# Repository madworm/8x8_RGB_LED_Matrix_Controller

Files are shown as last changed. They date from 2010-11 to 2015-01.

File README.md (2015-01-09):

8x8_RGB_LED_Matrix_Controller
=============================

LAYOUT FILES: 8x8-RGB-LED-Matrix controller using 4x 74HC595 shift registers. CPU: ATmega168/328. Arduino 'compatible'. Runs with code from [V3_x_boards_test](https://github.com/madworm/V3_x_boards_test) repo. KICAD and Gerber files.

---

Before having PC-boards made, please make sure you know about your manufacturer's peculiarities!
Especially drill-sizes and their tolerances may vary too much and give you trouble.

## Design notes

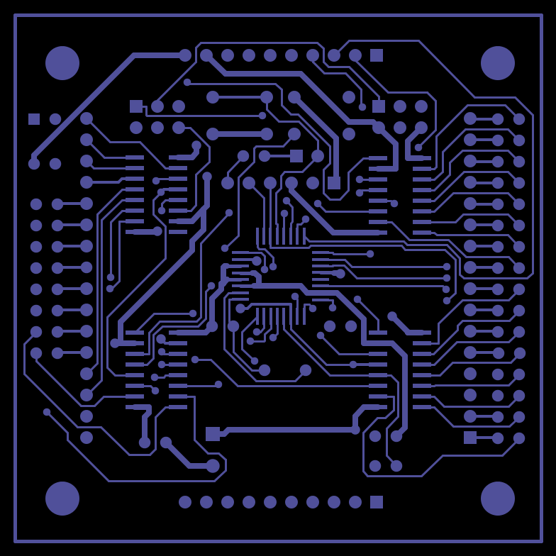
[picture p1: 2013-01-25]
gerber_files/PNGs/8x8_rgb_matrix-V3_04-Front.gtl.png

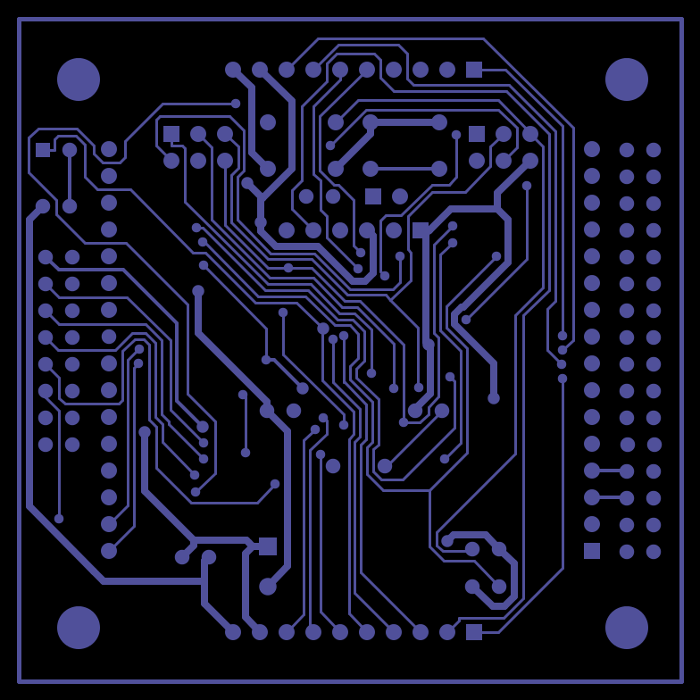
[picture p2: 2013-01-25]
gerber_files/PNGs/8x8_rgb_matrix-V3_04-Back.gbl.png

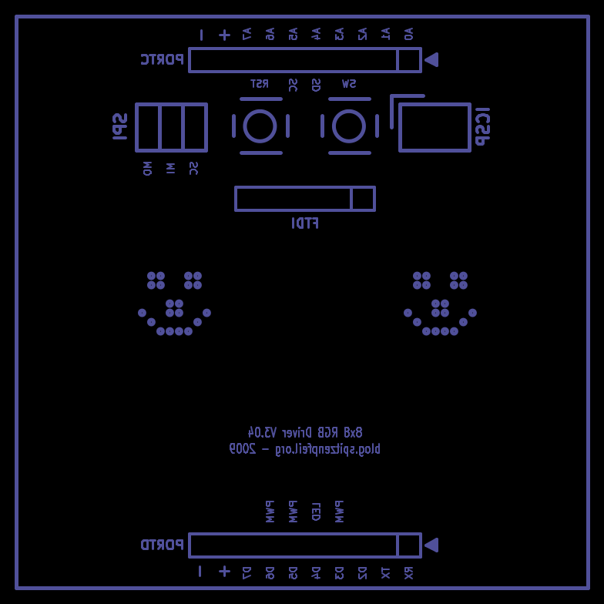
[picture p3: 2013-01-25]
gerber_files/PNGs/8x8_rgb_matrix-V3_04-B_SilkS.gbo.png

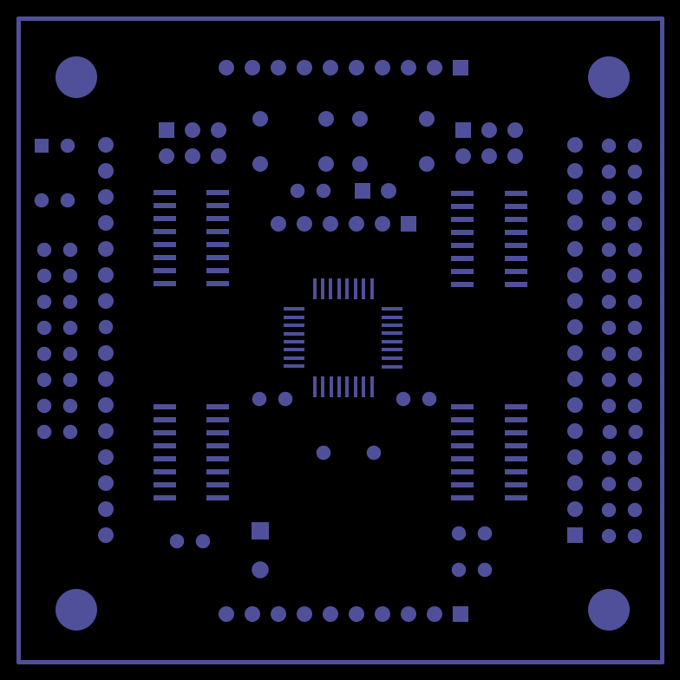
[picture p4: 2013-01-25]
gerber_files/PNGs/8x8_rgb_matrix-V3_04-F_Mask.gts.png

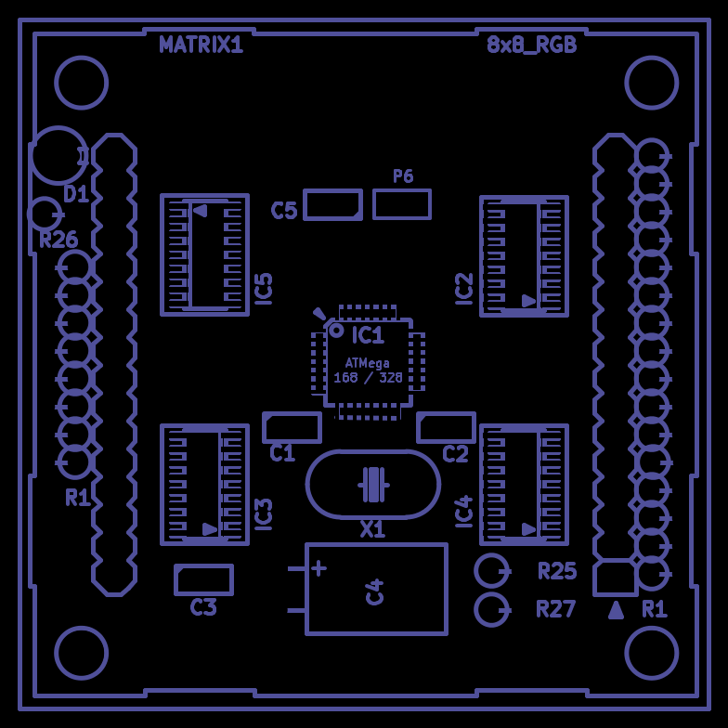
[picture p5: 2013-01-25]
gerber_files/PNGs/8x8_rgb_matrix-V3_04-F_SilkS.gto.png

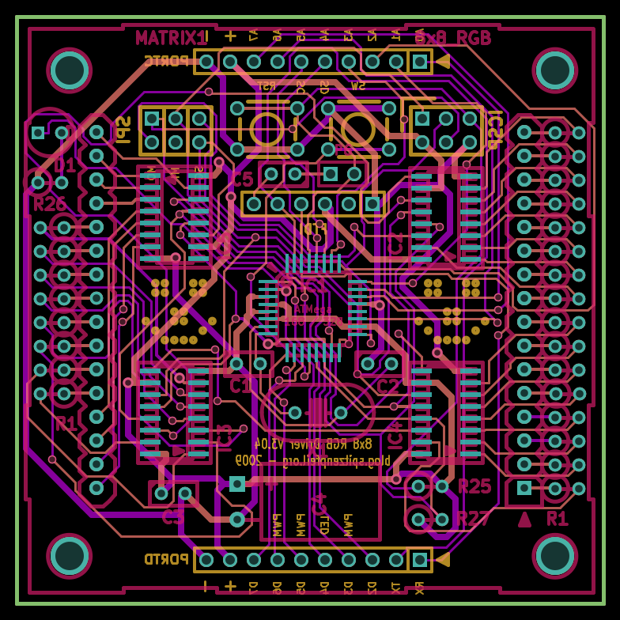
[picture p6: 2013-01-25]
gerber_files/PNGs/8x8_rgb_matrix-V3_04.png

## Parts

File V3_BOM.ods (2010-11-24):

Description: | Amount per board: | From: | Order part #: | Order amount: | Effective per board: | Rebate ? | Cost per part #: | Currency: | Effective per board: | Currency:
shipping costs for my orders | 1.000 | -- | -- | -- | 1.000 | -- | 2.350 | € | 2.350 | €
board | 1.000 | goldphoenix | __my_part__ | 10.000 | 1.000 | -- | 5.083 | € | 5.083 | €
led matrix | 1.000 | ledsee.com | RGBMATRIX | 10.000 | 1.000 | -- | 11.900 | € | 11.900 | €
10k Ohm | 2.000 | reichelt.de | METALL 10,0K | 20.000 | 2.000 | ab 1: 8.2 ¢, ab 10: 4.9¢, ab 100: 2.5¢, ab 1000: 1.6¢ | 0.049 | € | 0.098 | €
47µF | 1.000 | reichelt.de | RAD 47/35 | 10.000 | 1.000 | -- | 0.041 | € | 0.041 | €
100nF | 2.000 | reichelt.de | MKS-02 100N | 20.000 | 2.000 | -- | 0.120 | € | 0.240 | €
22pF | 2.000 | reichelt.de | KERKO 22P | 20.000 | 2.000 | -- | 0.040 | € | 0.080 | €
anti static bag | 0.010 | reichelt.de | ESD BEUTEL-P 150 | just once ! | 0.010 | -- | 6.000 | € | 0.060 | €
LED green 3mm | 1.000 | reichelt.de | LED 3MM GN | 10.000 | 1.000 | -- | 0.051 | € | 0.051 | €
270 Ohm | 24.000 | reichelt.de | METALL 270 | 240.000 | 24.000 | ab 1: 8.2 ¢, ab 10: 4.9¢, ab 100: 2.5¢, ab 1000: 1.6¢ | 0.025 | € | 0.600 | €
1k Ohm | 1.000 | reichelt.de | METALL 1,00K | 10.000 | 1.000 | ab 1: 8.2 ¢, ab 10: 4.9¢, ab 100: 2.5¢, ab 1000: 1.6¢ | 0.049 | € | 0.049 | €
quartz 16MHz | 1.000 | reichelt.de | 16,0000-HC49U-S | 10.000 | 1.000 | -- | 0.150 | € | 0.150 | €
3x2 male header | 2.000 | reichelt.de | SL 2X40G 2,54 | 2.000 | 0.150 | -- | 0.290 | € | 0.044 | €
10pin female header | 2.000 | reichelt.de | BL 1X10G8 2,54 | 20.000 | 2.000 | -- | 0.120 | € | 0.240 | €
74HC595 SMD | 4.000 | reichelt.de | SMD HC 595 | 40.000 | 4.000 | -- | 0.140 | € | 0.560 | €
lph switch | 2.000 | reichelt.de | TASTER 9302 | 20.000 | 2.000 | -- | 0.120 | € | 0.240 | €
6x1 male header | 1.000 | reichelt.de | SL 1X40G 2,54 | 2.000 | 0.150 | -- | 0.110 | € | 0.017 | €
2x1 male header | 1.000 | reichelt.de | SL 1X40G 2,54 | user leftovers ! | 0.050 | -- | 0.110 | € | 0.006 | €
atmega168 | 1.000 | segor.de | ATmega 168-20AU | 10.000 | 1.000 | ab 1: 4.00€, ab 10: 3.20€, ab 25: 2.80€ | 3.200 | € | 3.200 | €
8pin female precision header | 4.000 | segor.de | FLLAB 1x 8-180G | 40.000 | 4.000 | ab 1: 50¢, ab 10: 41¢, ab 25: 39¢ | 0.390 | € | 1.560 | €
quartz spacer | 1.000 | segor.de | Q-Isoscheibe | 10.000 | 1.000 | ab 1: 10¢, ab 10: 8¢ | 0.080 | € | 0.080 | €
low profile jumper h=4mm | 4.000 | segor.de | Mini-Jumper | 40.000 | 4.000 | ab 1: 10¢, ab 10: 8¢, ab 25: 8¢, ab 100: 7¢ | 0.080 | € | 0.320 | €
 |  |  |  |  |  |  |  | Total € | 26.967 |  | --> 28 €
 |  |  |  |  |  |  |  | € / USD | 1.330
 |  |  |  |  |  |  |  | Total USD | 35.867
Number of boards to make: |  | 10.000
Shipping costs reichelt.de |  | 5.900 | €
Shipping cost segor.de |  | 6.000 | € |  | 1x melka
Shpping cost ledsee.com |  | 11.603 | € |  | 1x nick
Shipping cost for my orders |  | 23.503 | € |  | 1x dra
 |  |  |  |  | 1x jason
last price update: OUTDATED !

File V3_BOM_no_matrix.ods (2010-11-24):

Description: | Amount per board: | From: | Order part #: | Order amount: | Effective per board: | Rebate ? | Cost per part #: | Currency: | Effective per board: | Currency:
shipping costs for my orders | 1.000 | -- | -- | -- | 1.000 | -- | 0.464 | € | 0.464 | €
board | 1.000 | goldphoenix | __my_part__ | 25.000 | 1.000 | -- | 5.083 | € | 5.083 | €
10k Ohm | 2.000 | reichelt.de | METALL 10,0K | 50.000 | 2.000 | ab 1: 8.2 ¢, ab 10: 4.9¢, ab 100: 2.5¢, ab 1000: 1.6¢ | 0.049 | € | 0.098 | €
47µF | 1.000 | reichelt.de | RAD 47/35 | 25.000 | 1.000 | -- | 0.040 | € | 0.040 | €
100nF | 2.000 | reichelt.de | MKS-02 100N | 50.000 | 2.000 | -- | 0.150 | € | 0.300 | €
22pF | 2.000 | reichelt.de | KERKO 22P | 50.000 | 2.000 | -- | 0.060 | € | 0.120 | €
anti static bag | 0.010 | reichelt.de | ESD BEUTEL-P 150 | just once ! | 0.010 | -- | 6.000 | € | 0.060 | €
LED green 3mm | 1.000 | reichelt.de | LED 3MM GN | 25.000 | 1.000 | -- | 0.060 | € | 0.060 | €
270 Ohm | 24.000 | reichelt.de | METALL 270 | 600.000 | 24.000 | ab 1: 8.2 ¢, ab 10: 4.9¢, ab 100: 2.5¢, ab 1000: 1.6¢ | 0.025 | € | 0.600 | €
1k Ohm | 1.000 | reichelt.de | METALL 1,00K | 25.000 | 1.000 | ab 1: 8.2 ¢, ab 10: 4.9¢, ab 100: 2.5¢, ab 1000: 1.6¢ | 0.049 | € | 0.049 | €
quartz 16MHz | 1.000 | reichelt.de | 16,0000-HC49U-S | 25.000 | 1.000 | -- | 0.180 | € | 0.180 | €
3x2 male header | 2.000 | reichelt.de | SL 2X40G 2,54 | 4.000 | 0.150 | -- | 0.270 | € | 0.041 | €
10pin female header | 2.000 | reichelt.de | BL 1X10G8 2,54 | 50.000 | 2.000 | -- | 0.140 | € | 0.280 | €
74HC595 SMD | 4.000 | reichelt.de | SMD HC 595 | 100.000 | 4.000 | -- | 0.170 | € | 0.680 | €
lph switch | 2.000 | reichelt.de | TASTER 9302 | 50.000 | 2.000 | -- | 0.130 | € | 0.260 | €
6x1 male header | 1.000 | reichelt.de | SL 1X40G 2,54 | 5.000 | 0.150 | -- | 0.120 | € | 0.018 | €
2x1 male header | 1.000 | reichelt.de | SL 1X40G 2,54 | user leftovers ! | 0.050 | -- | 0.120 | € | 0.006 | €
atmega168 | 1.000 | segor.de | ATmega 168-20AU | 25.000 | 1.000 | ab 1: 4.00€, ab 10: 3.20€, ab 25: 2.80€ | 2.800 | € | 2.800 | €
8pin female precision header | 4.000 | segor.de | FLLAB 1x 8-180G | 100.000 | 4.000 | ab 1: 50¢, ab 10: 40¢, ab 25: 38¢, ab 100: 35¢ | 0.350 | € | 1.400 | €
quartz spacer | 1.000 | segor.de | Q-Isoscheibe | 25.000 | 1.000 | ab 1: 10¢, ab 10: 8¢ | 0.080 | € | 0.080 | €
low profile jumper h=4mm | 4.000 | segor.de | Mini-Jumper | 100.000 | 4.000 | ab 1: 10¢, ab 10: 8¢, ab 25: 8¢, ab 100: 7¢ | 0.080 | € | 0.320 | €
 |  |  |  |  |  |  |  | Total € | 12.938 |  | --> 16.50 €
 |  |  |  |  |  |  |  | € / USD | 1.330
 |  |  |  |  |  |  |  | Total USD | 17.208
Number of boards to make: |  | 25.000
Shipping costs reichelt.de |  | 5.600 | €
Shipping cost segor.de |  | 6.000 | €
Shipping cost for my orders |  | 11.600 | €
last price update: 06-07-2009

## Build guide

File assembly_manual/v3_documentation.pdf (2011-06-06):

V3.x Matrix Controller assembly instructions

### 1. List of Parts:

- IC1 | Atmega168-20AU, TQFP 32 7x7 ( Mouser: 556-ATMEGA168-20AU )
- IC2-5 | 74HC595, ST EZ80731, SO16
- C1-2 | 22pF, should match X1
- C3,C5 | 100nF ( Mouser: 505-MKS02.1/63/10 )
- C4 | 47µF ( Mouser: 75-515D474M050JA6AE3 )
- R25,R27 | 10k
- R26 | 1k
- D1 | LED, 3mm
- RE | reset enable, 2pin male header (cut to size) + low profile jumper
- R1-24 | suitable resistors for RGB LEDs. 270Ω may work for all
- MATRIX | 4x 8pin female header
- PORTC/D | 2x 10pin female header
- ICSP | 1x 2x3pin male header
- SPI | 1x 2x3pin male header + 3 jumper
- SW,RST | general purpose switch, Schurter 1301.9302 ( Farnell: 1217773 )
- FTDI | 6pin male header
- X1 | 16MHz Quartz, HC49U-S package, low profile ! ( Mouser: 520-HCU1600-SX )
- spacer | Quartz spacer, non conductive ( or piece of plastic under the quartz, e.g. laser transparency )

When you buy the parts, make sure none of the components consume more than 7.5mm of height when assembled. Depending on the type of LED matrix you use, “standing” through hole resistors may have to be bent sideways at an angle of about 20-30°. Using small size resistors is an alternative if you can get them.

### 2. You will need:

- Soldering iron with a tip suitable for 0.5-0.8mm traces, not too small
- Solder with flux core, preferably "no clean", about 0.5-0.8mm diameter
- Additional "no clean" flux, in a syringe or dispenser pen
- wire cutter, tweezers
- strong magnifier for solder joint inspection
- cotton swabs + isopropyl alcohol for removing residual flux
- Programmer to flash the bootloader. Adafruit.com USBtinyISP works just fine
- USB/TTL serial adapter with DTR for auto-reset

### 3. Tips:

- Align the SMD parts as good as possible or you will have "lots of fun"
- Always use plenty of flux
- Always clean the tip
- Don't rush it

### 4. Suggested assembly steps:

- Start with the first group of parts with numbers 1 – 6 to build a minimal working system
- Flash the bootloader
- Continue to attach the remaining 4 SMT chips in group 7
- Now just follow the numbers until done.

If you want to change the order of attaching parts I'd put on the SMT chips first. If you put them on after the headers and other through hole parts you'll have "a lot of fun" while avoiding to burn holes into various components.

### 5. Suggested USB/TTL serial adapters:

- ModernDevice "BUB" ( http://www.moderndevice.com )
- Sparkfun "FTDI Basic Breakout – 5V" ( http://www.sparkfun.com )
- FTDI cable FTDI-TTL-232R-3V3 (works too, but no auto-reset)

### 6. Compatible RGB LED matrices:

- http://stores.ebay.com/LEDSEE-electronics
- http://www.seeedstudio.com

### 7. Please avoid:

- applying more than 5V DC (regulated) may destroy the device terminally
- do not reverse polarization of the USB adapter (pin 1 = GND)
- shorting pins to 5V/GND when set as OUTPUT may destroy the pin / chip
- do not power solenoids / relays without a transistor / protection diode
- in case of doubt, use a 1k resistor instead of just a blank wire
- isopropyl alcohol may decompose the transparent resin of the LED matrix

### 8. Pin assignment:

- The LED is connected to PD4 / digital IN/OUT 4
- The general purpose button is connected to PB0 / digital IN/OUT 8
- I²C / TWI (two wire): SDA, SCL

“PORTC” :

“PORTD” :

PIN NAME FUNCTION ARDUINO PIN | ARDUINO PIN
1 | PC0 | ADC0 | analog IN 0 digital IN/OUT 14
2 | PC1 | ADC1 | analog IN 1 digital IN/OUT 15
3 | PC2 | ADC2 | analog IN 2 digital IN/OUT 16
4 | PC3 | ADC3 | analog IN 3 digital IN/OUT 17
5 | PC4 ADC4, SDA analog IN 4 digital IN/OUT 18
6 | PC5 ADC5, SCL analog IN 5 digital IN/OUT 19
7 ADC6 | ADC6 | analog IN 6 | -
8 ADC7 | ADC7 | analog IN 7 | -
9 | + | 5V | - | -
10 | - | GND | - | -
PIN NAME | FUNCTION | ARDUINO PIN | ARDUINO PIN
1 | PD0 | RXD | RXD | digital IN/OUT 0
2 | PD1 | TXD | TXD | digital IN/OUT 1
3 | PD2 | INT0 | - | digital IN/OUT 2
4 | PD3 | INT1, OC2B | PWM | digital IN/OUT 3
5 | PD4 | XCK, T0 | onboard LED digital IN/OUT 4
6 | PD5 | T1, OC0B | PWM | digital IN/OUT 5
7 | PD6 | AIN0, OC0A | PWM | digital IN/OUT 6
8 | PD7 | AIN1 | - | digital IN/OUT 7
9 | + | 5V | - | -
10 | - | GND | - | -

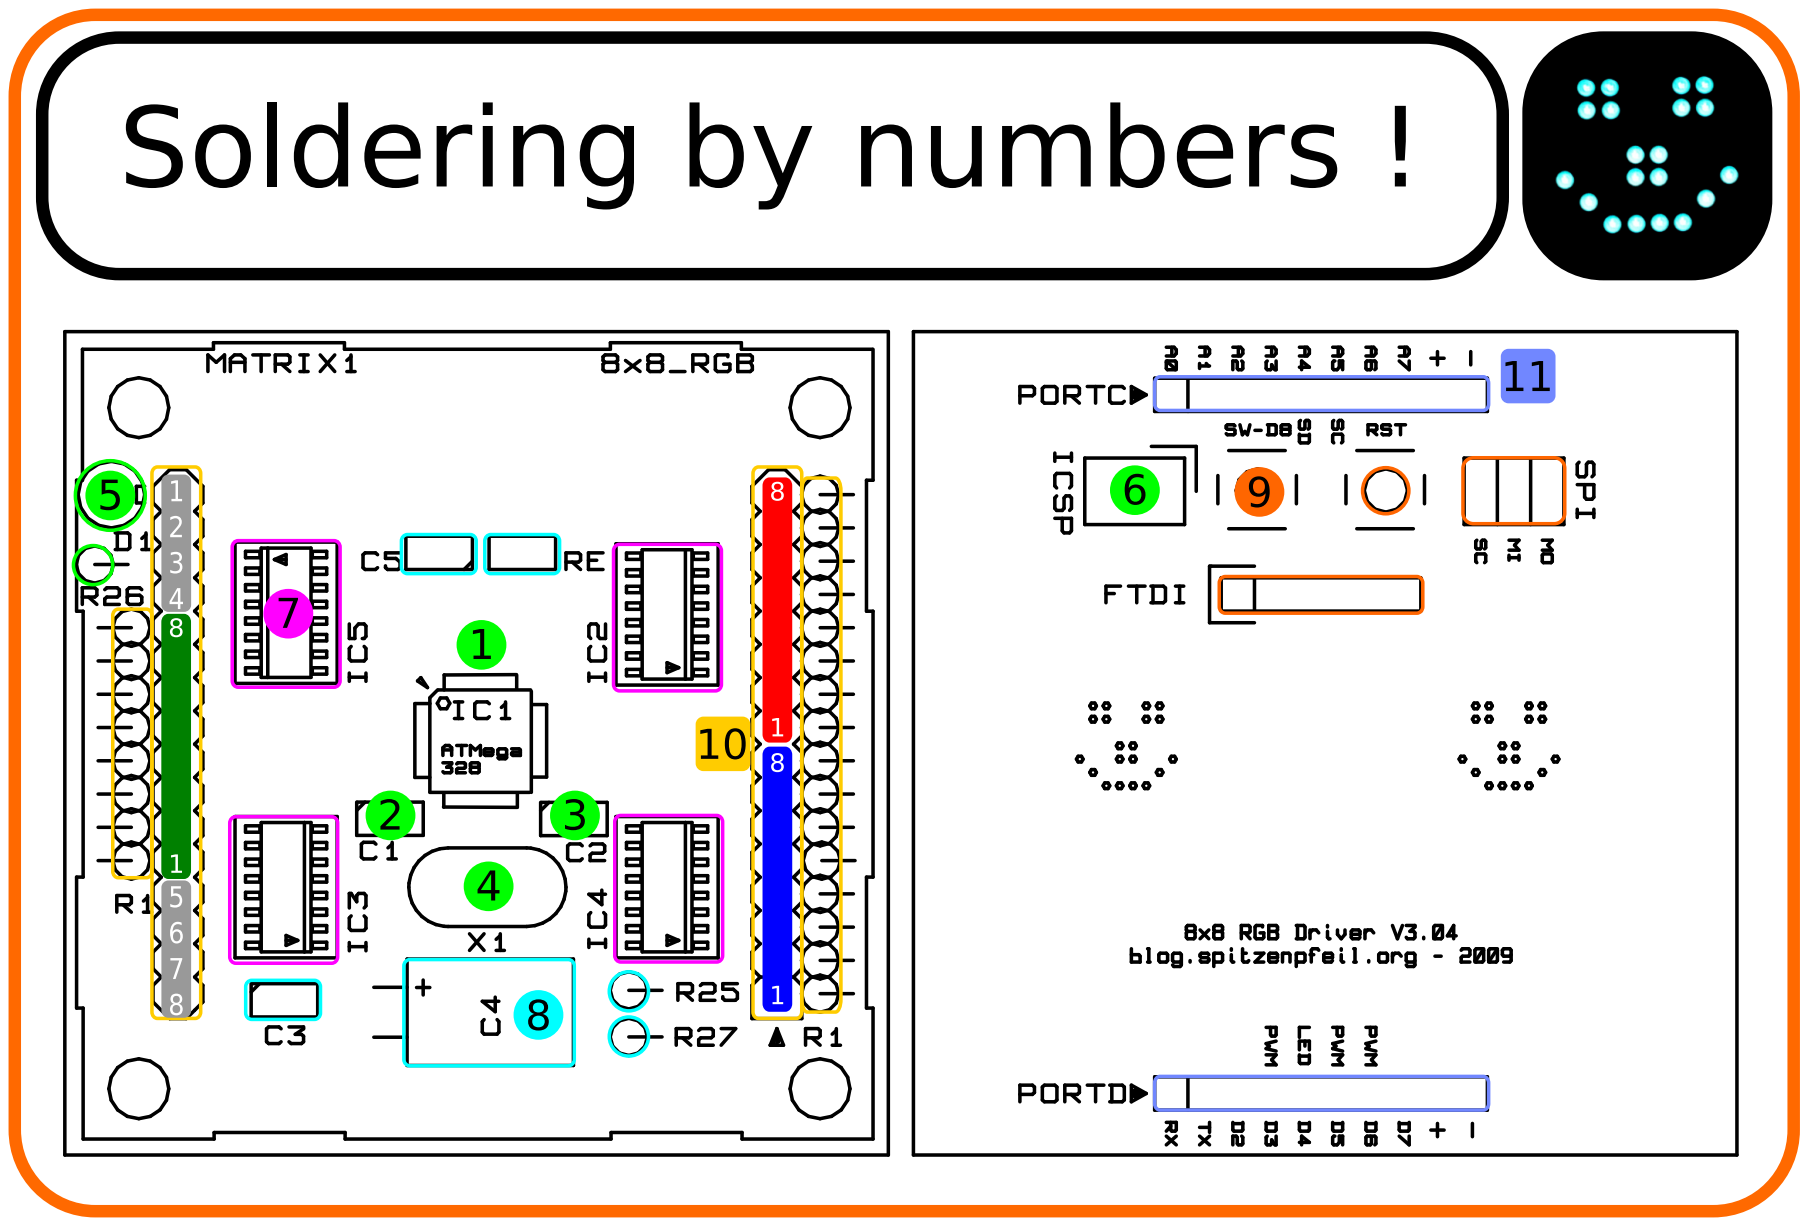
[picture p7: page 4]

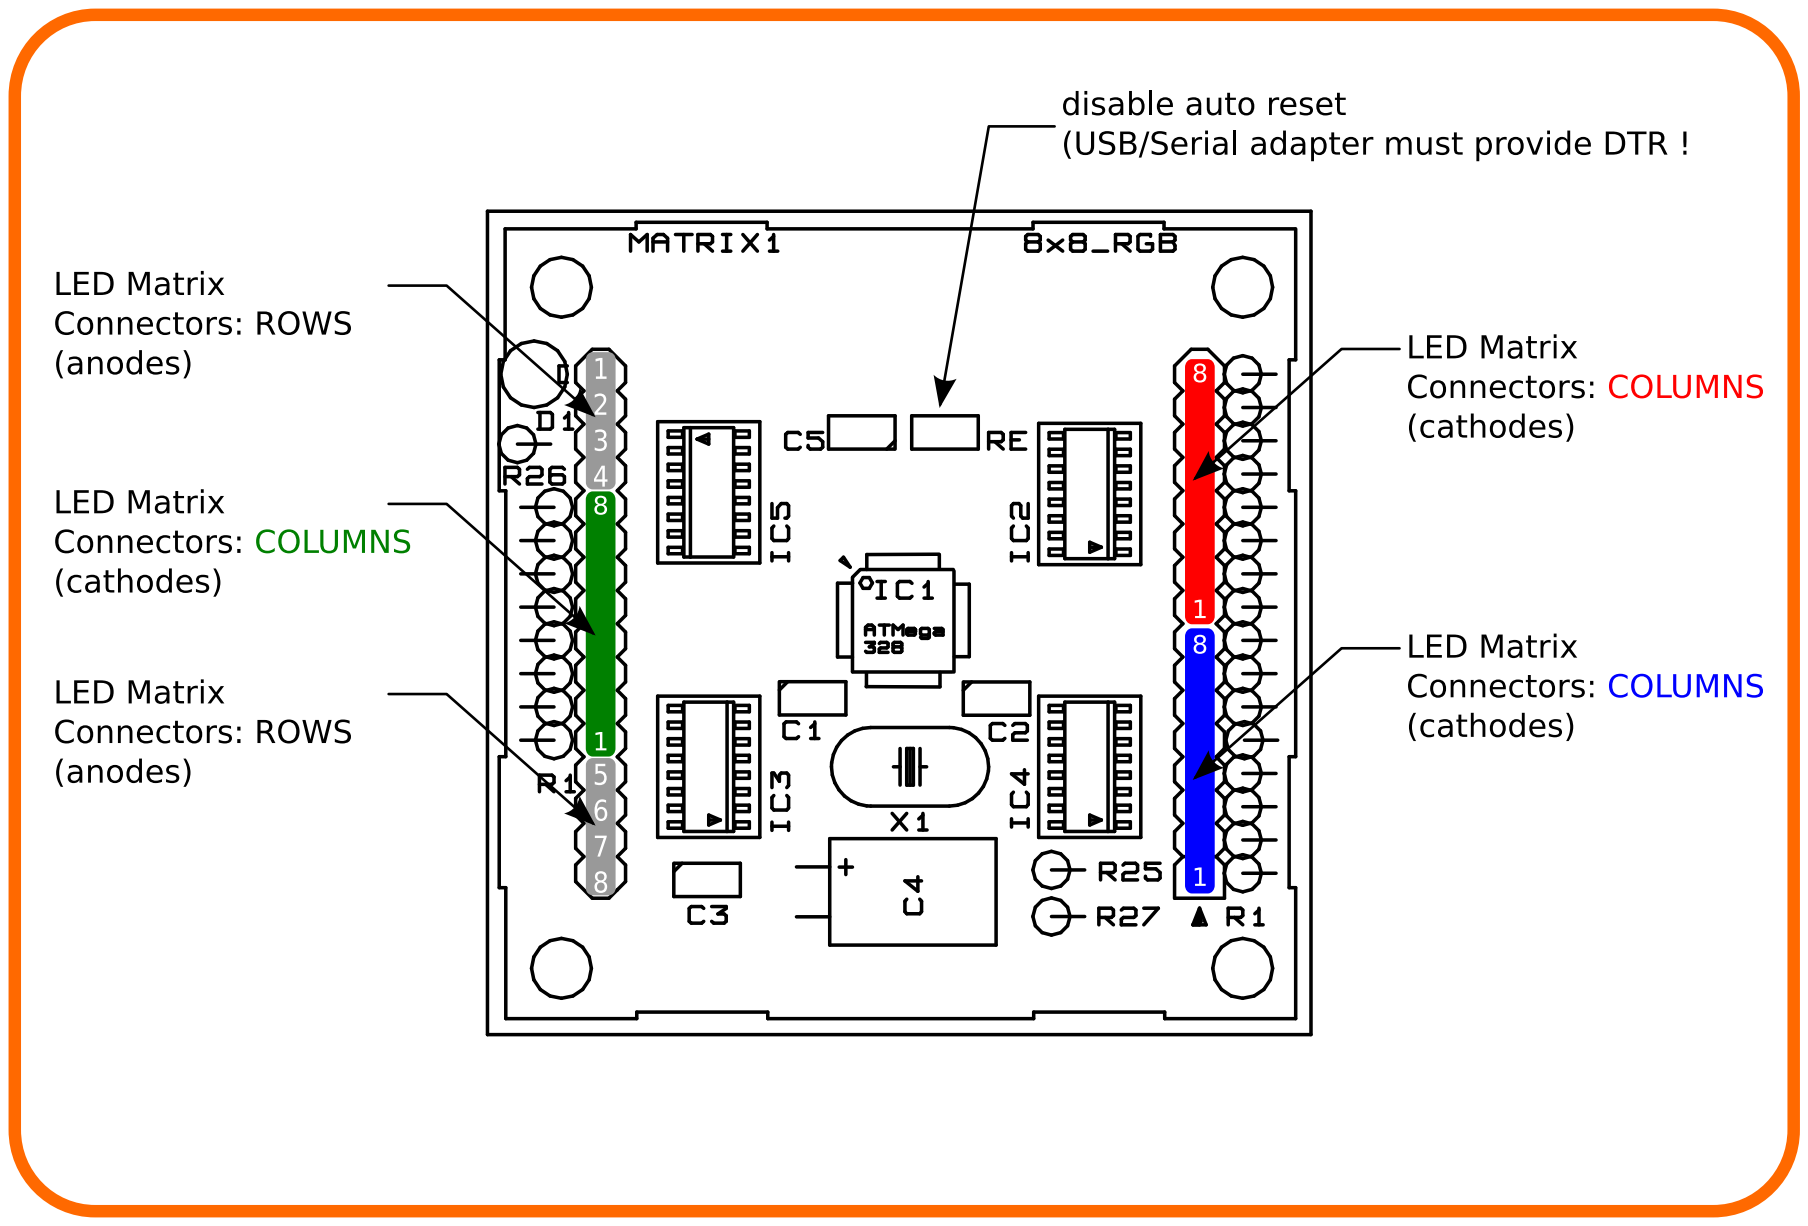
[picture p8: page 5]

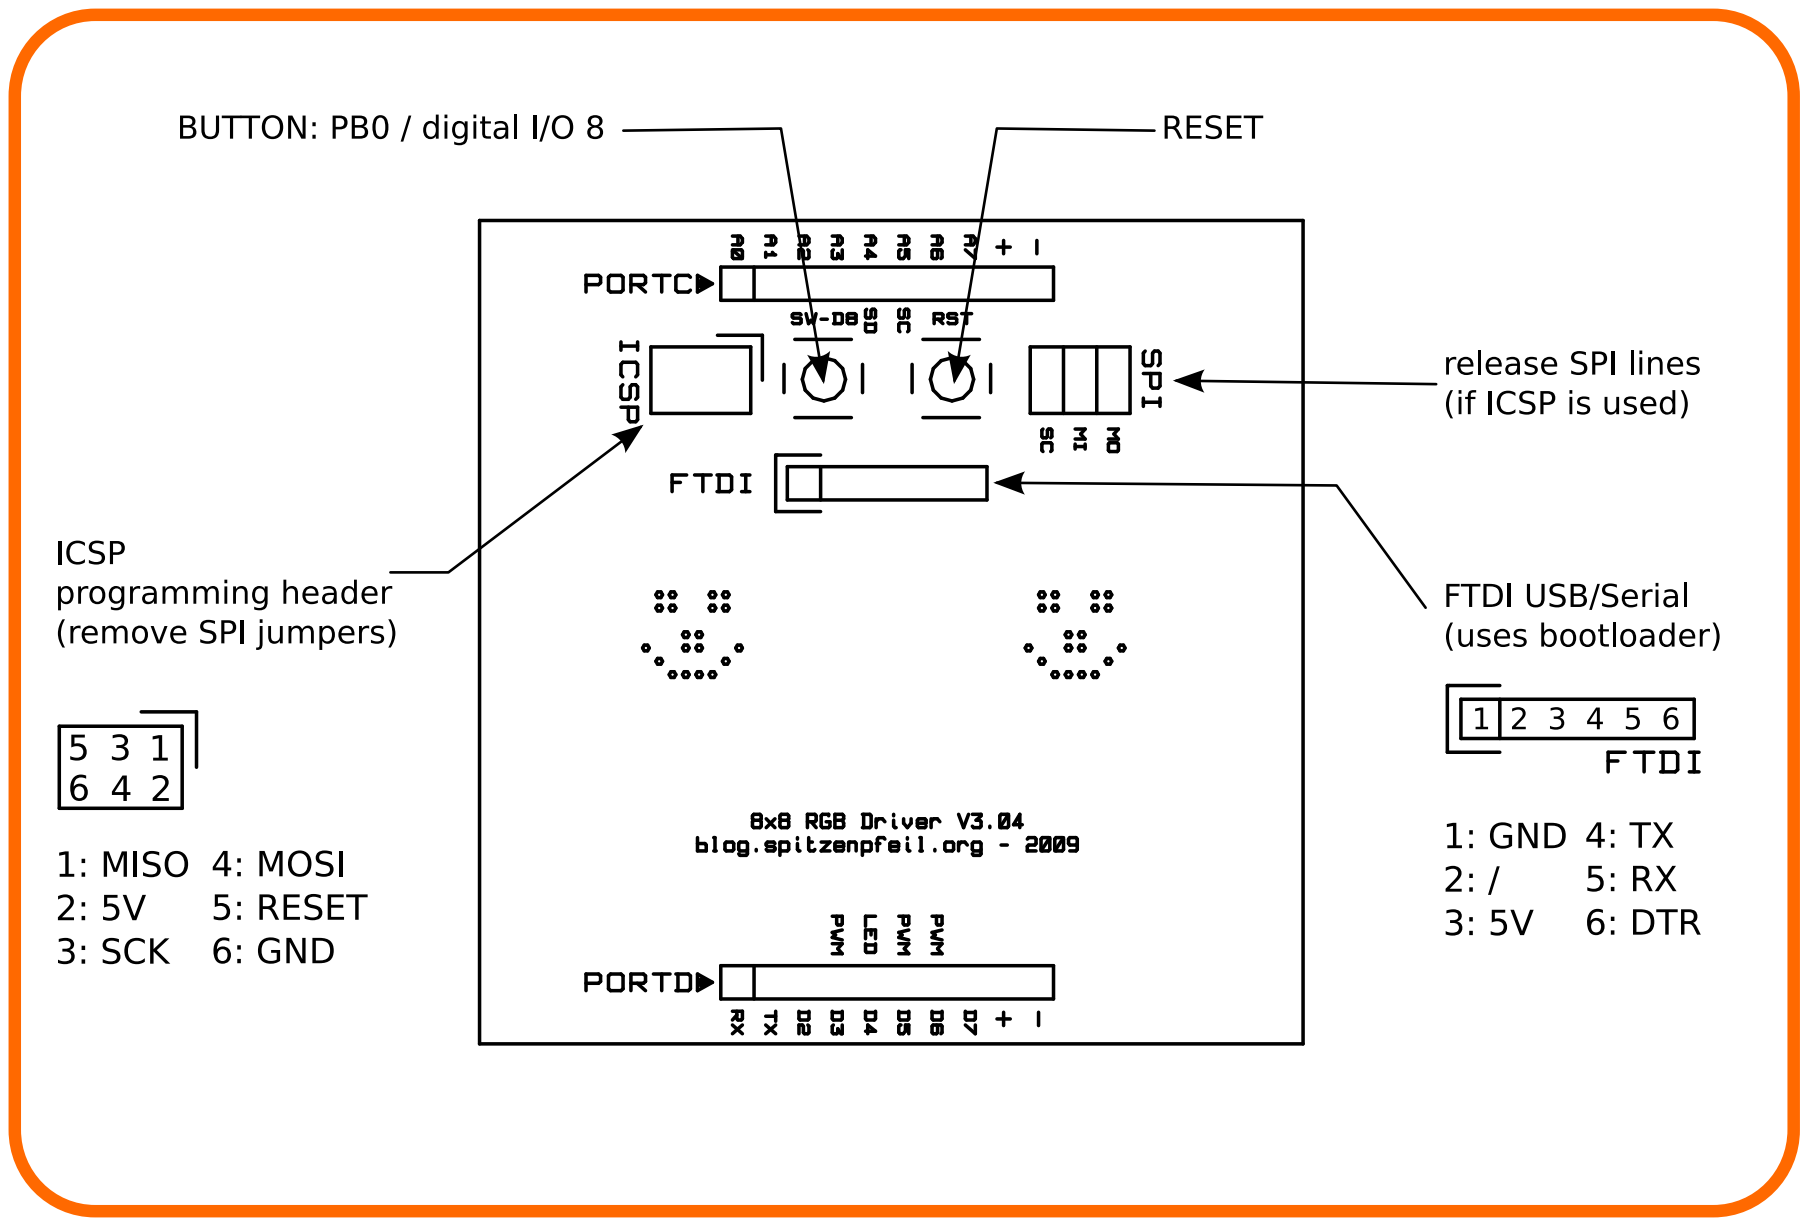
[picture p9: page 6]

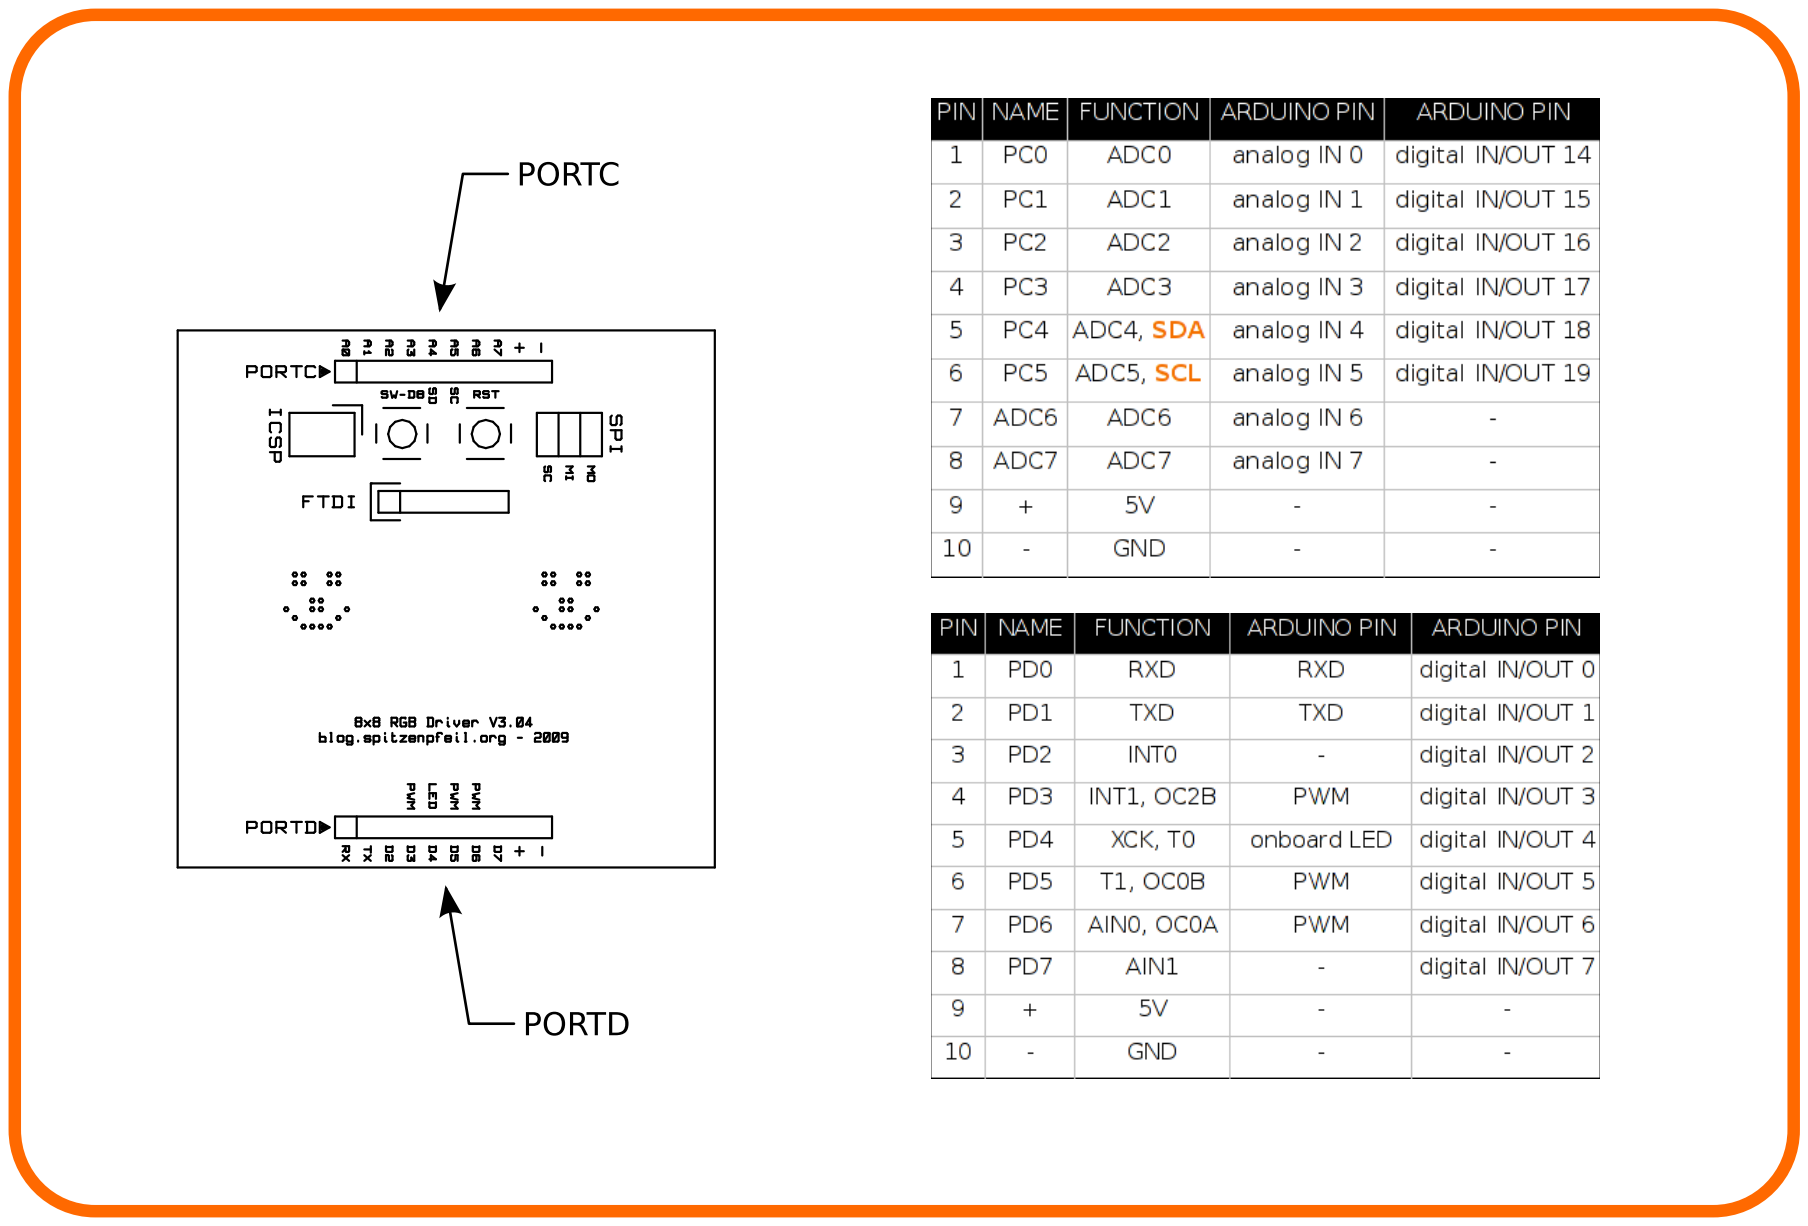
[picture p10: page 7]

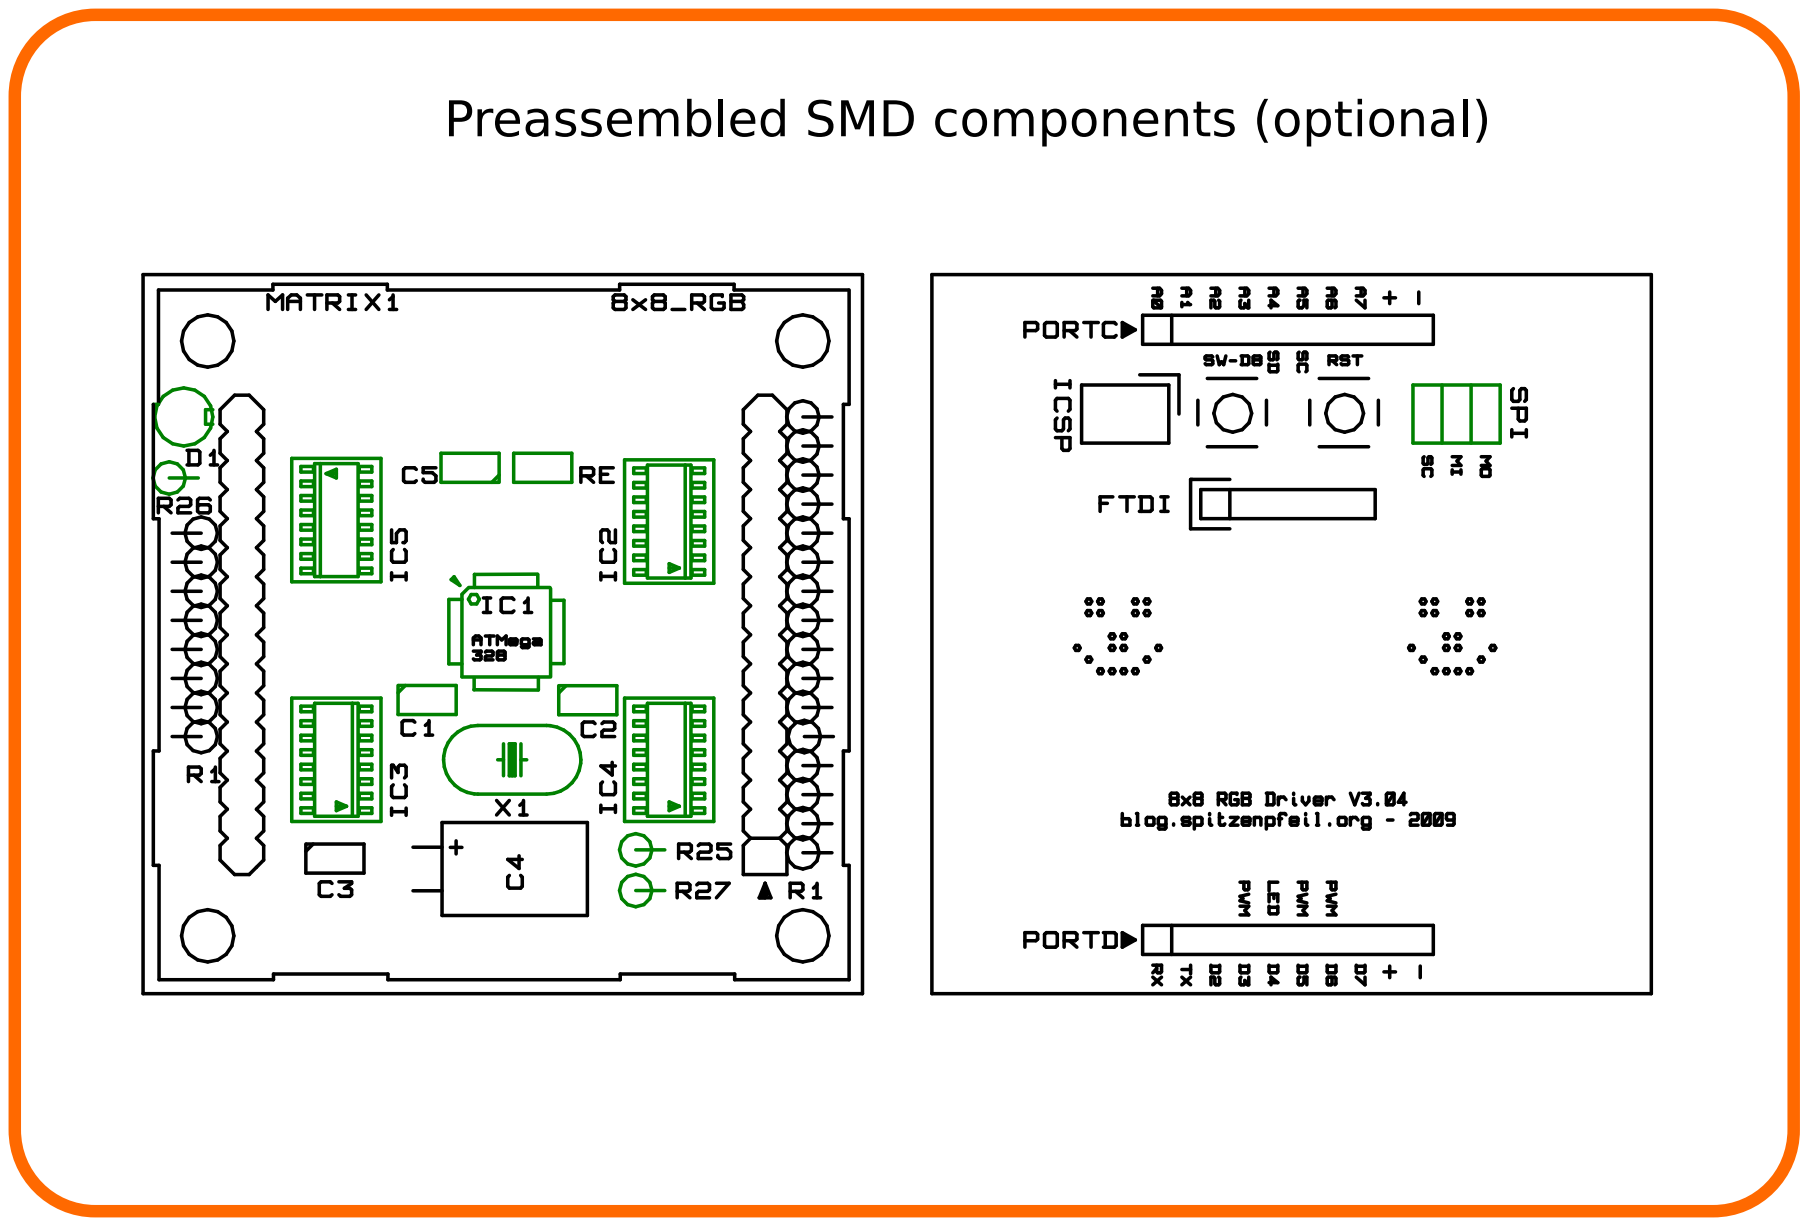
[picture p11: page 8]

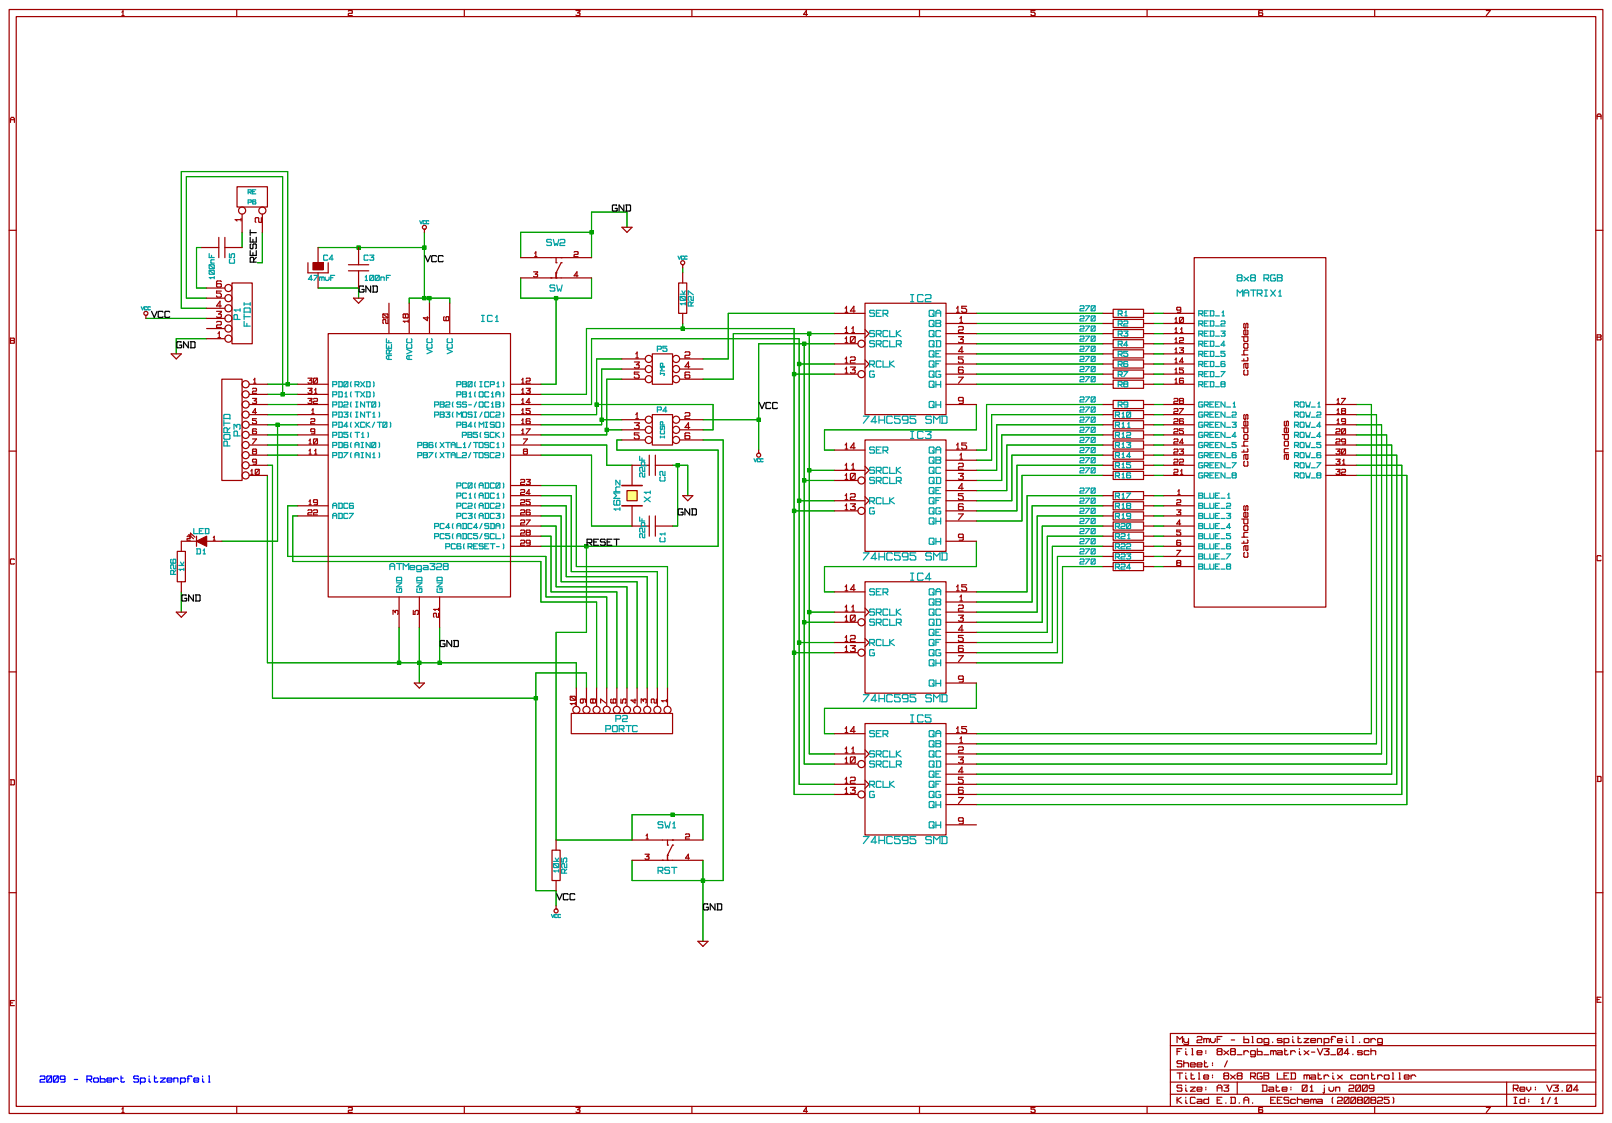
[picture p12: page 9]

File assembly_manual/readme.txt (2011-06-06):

Demo code can be found in the 'V3_x_boards_test' repository

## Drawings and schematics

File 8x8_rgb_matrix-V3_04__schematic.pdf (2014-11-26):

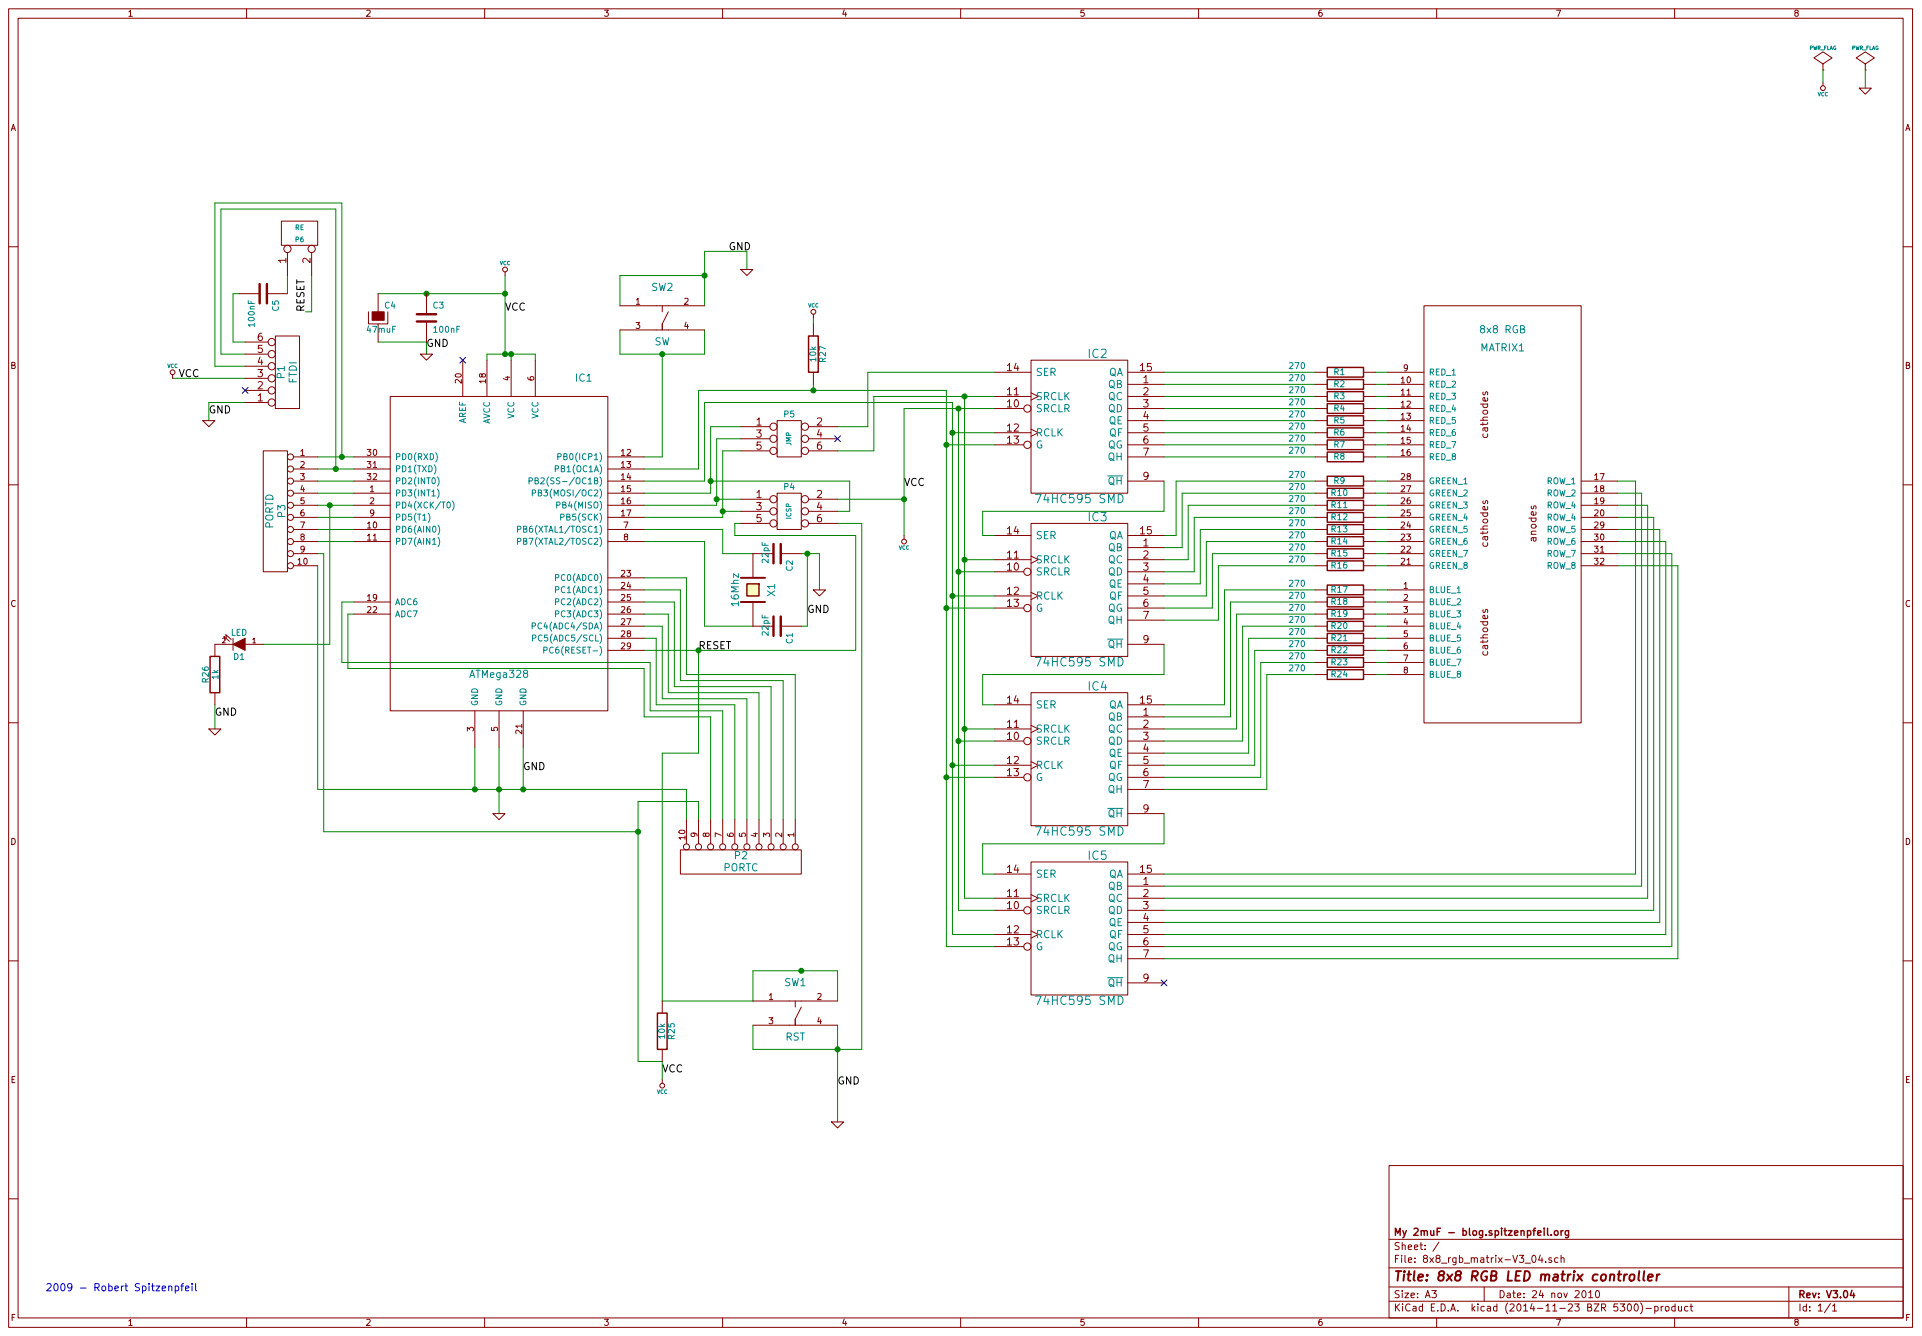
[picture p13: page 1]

File: 8x8_rgb_matrix-V3_04.sch Sheet: / My 2muF - blog.spitzenpfeil.org

Id: 1/1 Title: 8x8 RGB LED matrix controller

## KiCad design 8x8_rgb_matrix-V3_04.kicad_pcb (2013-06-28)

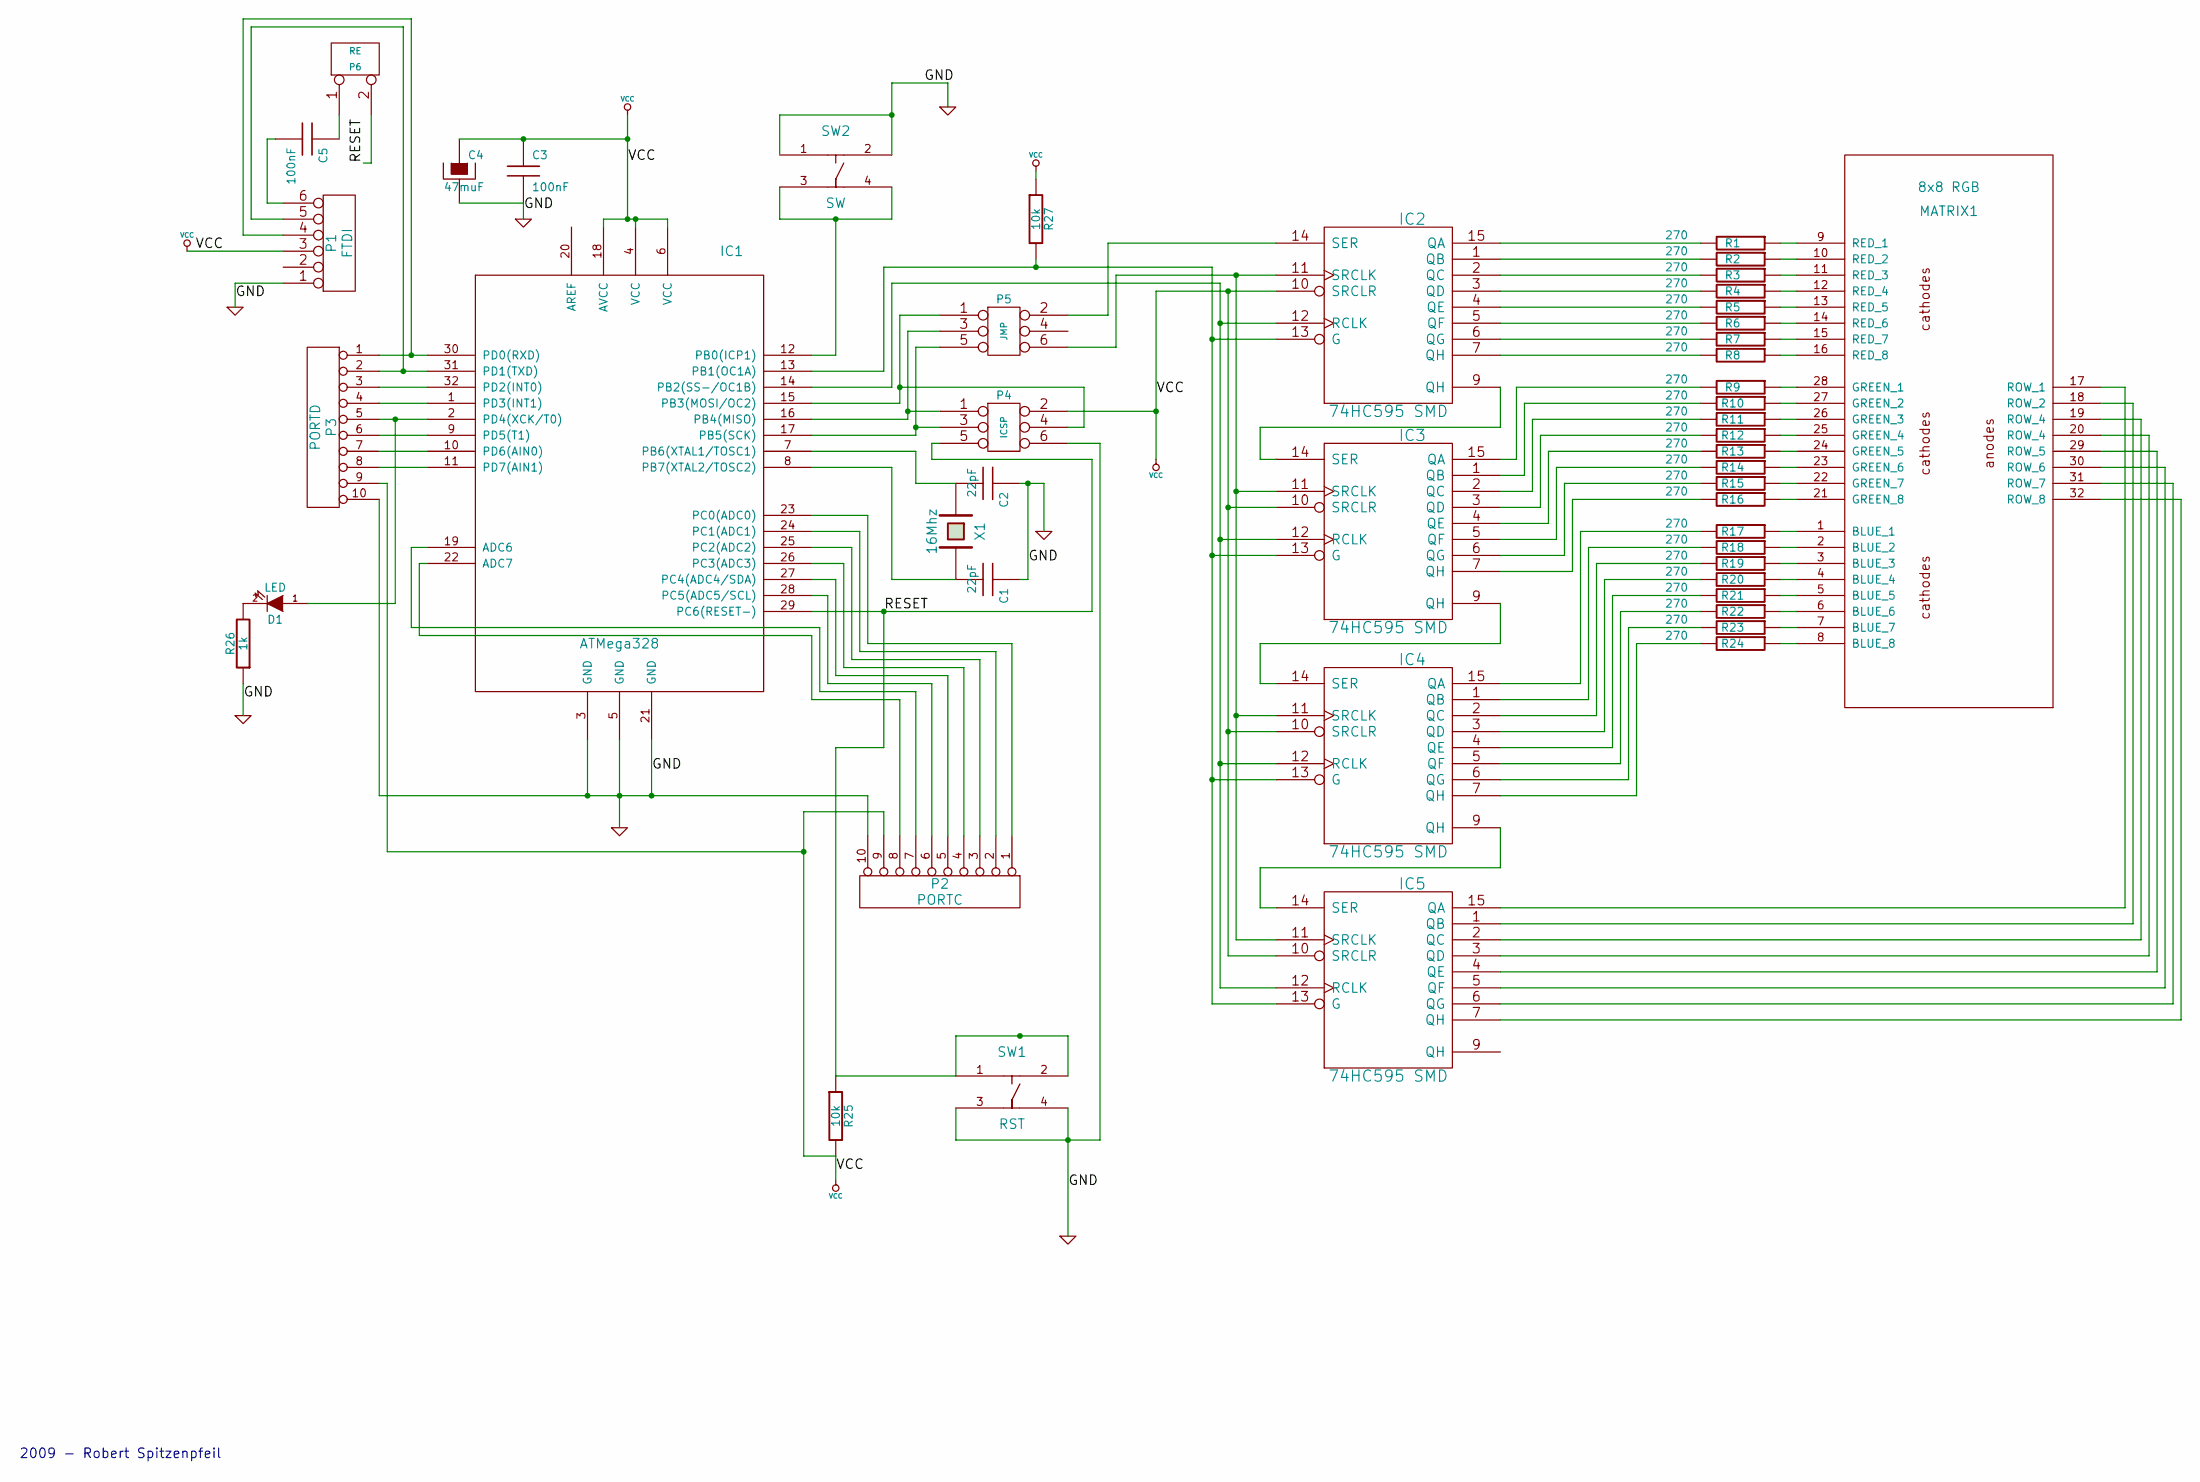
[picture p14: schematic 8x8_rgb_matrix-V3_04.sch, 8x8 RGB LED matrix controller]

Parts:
C1, C2: 22pF
C3, C5: 100nF
C4: 47muF
D1: LED
IC1: ATMega328
IC2, IC3, IC4, IC5: 74HC595 SMD
MATRIX1: 8x8 RGB
P1: FTDI
P2: PORTC
P3: PORTD
P4: ICSP
P5: JMP
P6: RE
R1, R2, R3, R4, R5, R6, R7, R8, R9, R10, R11, R12, R13, R14, R15, R16, R17, R18, R19, R20, R21, R22, R23, R24: 270
R25, R27: 10k
R26: 1k
SW1: RST
SW2: SW
X1: 16Mhz

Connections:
/GND: C1.1, C2.1, C3.2, C4.2, IC1.3 (GND), IC1.5 (GND), IC1.21 (GND), IC2.8 (GND), IC3.8 (GND), IC4.8 (GND), IC5.8 (GND), P1.1, P2.10, P3.10, P4.6, R26.1, SW1.3, SW1.4, SW2.1, SW2.2
/RESET: IC1.29 (PC6(RESET-)), P4.5, P6.2 (PM), R25.1, SW1.1, SW1.2
unnamed: IC1.16 (PB4(MISO)), P4.1, P5.3
unnamed: IC1.30 (PD0(RXD)), P1.4, P3.1
unnamed: C5.1, P6.1
unnamed: C5.2, P1.6
unnamed: C1.2, IC1.8 (PB7(XTAL2/TOSC2)), X1.2
unnamed: IC1.28 (PC5(ADC5/SCL)), P2.6
unnamed: IC1.26 (PC3(ADC3)), P2.4
unnamed: IC1.24 (PC1(ADC1)), P2.2
unnamed: IC2.14 (SER), P5.2
unnamed: IC1.22 (ADC7), P2.8
unnamed: IC1.19 (ADC6), P2.7
unnamed: D1.1 (A), IC1.2 (PD4(XCK/T0)), P3.5
unnamed: IC1.11 (PD7(AIN1)), P3.8
unnamed: IC1.9 (PD5(T1)), P3.6
unnamed: IC1.1 (PD3(INT1)), P3.4
unnamed: IC5.7 (QH), MATRIX1.32 (ROW_8)
unnamed: IC5.5 (QF), MATRIX1.30 (ROW_6)
unnamed: IC5.3 (QD), MATRIX1.20 (ROW_4)
unnamed: IC5.1 (QB), MATRIX1.18 (ROW_2)
unnamed: IC2.7 (QH), R8.2
unnamed: IC2.5 (QF), R6.2
unnamed: IC2.3 (QD), R4.2
unnamed: IC2.1 (QB), R2.2
unnamed: IC3.15 (QA), R9.2
unnamed: IC3.2 (QC), R11.2
unnamed: IC3.4 (QE), R13.2
unnamed: IC3.6 (QG), R15.2
unnamed: MATRIX1.8 (BLUE_8), R24.1
unnamed: MATRIX1.6 (BLUE_6), R22.1
unnamed: MATRIX1.4 (BLUE_4), R20.1
unnamed: MATRIX1.2 (BLUE_2), R18.1
unnamed: MATRIX1.21 (GREEN_8), R16.1
unnamed: MATRIX1.23 (GREEN_6), R14.1
unnamed: MATRIX1.25 (GREEN_4), R12.1
unnamed: MATRIX1.27 (GREEN_2), R10.1
unnamed: MATRIX1.16 (RED_8), R8.1
unnamed: MATRIX1.14 (RED_6), R6.1
unnamed: MATRIX1.12 (RED_4), R4.1
unnamed: MATRIX1.10 (RED_2), R2.1
unnamed: IC4.9 (QH), IC5.14 (SER)
unnamed: IC4.6 (QG), R23.2
unnamed: IC4.4 (QE), R21.2
unnamed: IC4.2 (QC), R19.2
unnamed: IC4.15 (QA), R17.2
unnamed: IC3.7 (QH), R16.2
unnamed: IC2.9 (QH), IC3.14 (SER)
unnamed: IC3.1 (QB), R10.2
unnamed: IC3.3 (QD), R12.2
unnamed: IC3.5 (QF), R14.2
unnamed: IC3.9 (QH), IC4.14 (SER)
unnamed: IC4.1 (QB), R18.2
unnamed: IC4.3 (QD), R20.2
unnamed: IC4.5 (QF), R22.2
unnamed: IC4.7 (QH), R24.2
unnamed: MATRIX1.9 (RED_1), R1.1
unnamed: MATRIX1.11 (RED_3), R3.1
unnamed: MATRIX1.13 (RED_5), R5.1
unnamed: MATRIX1.15 (RED_7), R7.1
unnamed: MATRIX1.28 (GREEN_1), R9.1
unnamed: MATRIX1.26 (GREEN_3), R11.1
unnamed: MATRIX1.24 (GREEN_5), R13.1
unnamed: MATRIX1.22 (GREEN_7), R15.1
unnamed: MATRIX1.1 (BLUE_1), R17.1
unnamed: MATRIX1.3 (BLUE_3), R19.1
unnamed: MATRIX1.5 (BLUE_5), R21.1
unnamed: MATRIX1.7 (BLUE_7), R23.1
unnamed: IC2.15 (QA), R1.2
unnamed: IC2.2 (QC), R3.2
unnamed: IC2.4 (QE), R5.2
unnamed: IC2.6 (QG), R7.2
unnamed: IC5.15 (QA), MATRIX1.17 (ROW_1)
unnamed: IC5.2 (QC), MATRIX1.19 (ROW_4)
unnamed: IC5.4 (QE), MATRIX1.29 (ROW_5)
unnamed: IC5.6 (QG), MATRIX1.31 (ROW_7)
unnamed: IC1.31 (PD1(TXD)), P1.5, P3.2
unnamed: IC1.32 (PD2(INT0)), P3.3
unnamed: IC1.10 (PD6(AIN0)), P3.7
unnamed: IC1.15 (PB3(MOSI/OC2)), P4.4, P5.1
unnamed: IC1.14 (PB2(SS-/OC1B)), IC2.12 (RCLK), IC3.12 (RCLK), IC4.12 (RCLK), IC5.12 (RCLK)
unnamed: IC2.11 (SRCLK), IC3.11 (SRCLK), IC4.11 (SRCLK), IC5.11 (SRCLK), P5.6
unnamed: IC1.17 (PB5(SCK)), P4.3, P5.5
unnamed: IC1.13 (PB1(OC1A)), IC2.13 (G), IC3.13 (G), IC4.13 (G), IC5.13 (G), R27.2
unnamed: IC1.12 (PB0(ICP1)), SW2.3, SW2.4
unnamed: IC1.23 (PC0(ADC0)), P2.1
unnamed: IC1.25 (PC2(ADC2)), P2.3
unnamed: IC1.27 (PC4(ADC4/SDA)), P2.5
unnamed: C2.2, IC1.7 (PB6(XTAL1/TOSC1)), X1.1
unnamed: D1.2 (K), R26.2
VCC: C3.1, C4.1, IC1.4 (VCC), IC1.6 (VCC), IC1.18 (AVCC), IC2.10 (SRCLR), IC2.16 (VCC), IC3.10 (SRCLR), IC3.16 (VCC), IC4.10 (SRCLR), IC4.16 (VCC), IC5.10 (SRCLR), IC5.16 (VCC), P1.3, P2.9, P3.9, P4.2, R25.2, R27.1

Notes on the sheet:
2009 - Robert Spitzenpfeil

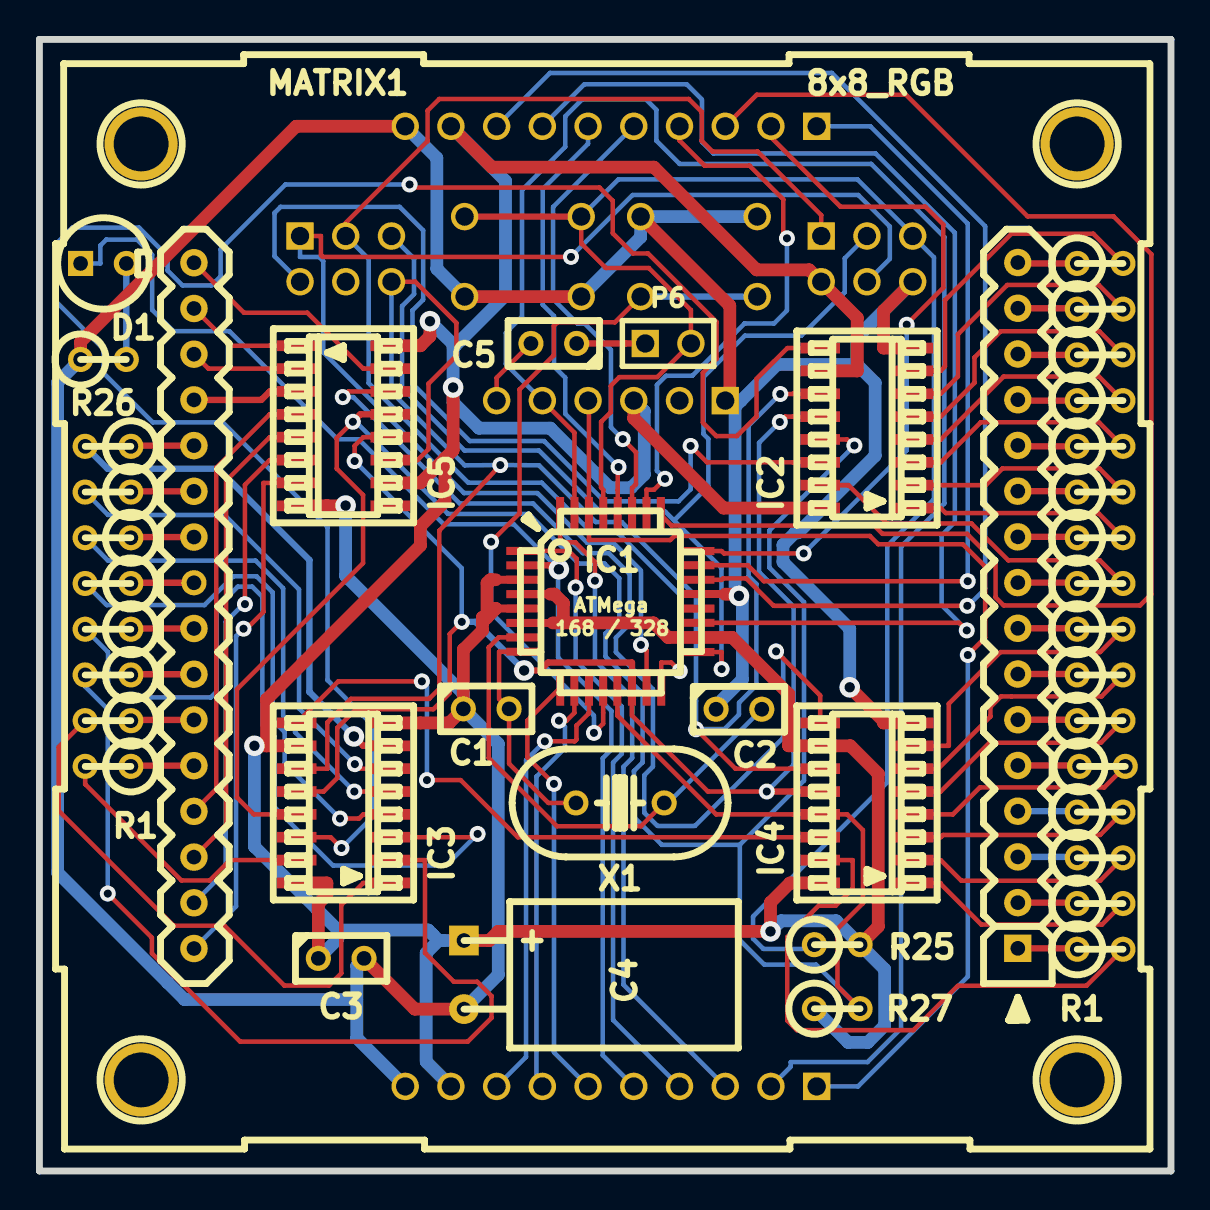
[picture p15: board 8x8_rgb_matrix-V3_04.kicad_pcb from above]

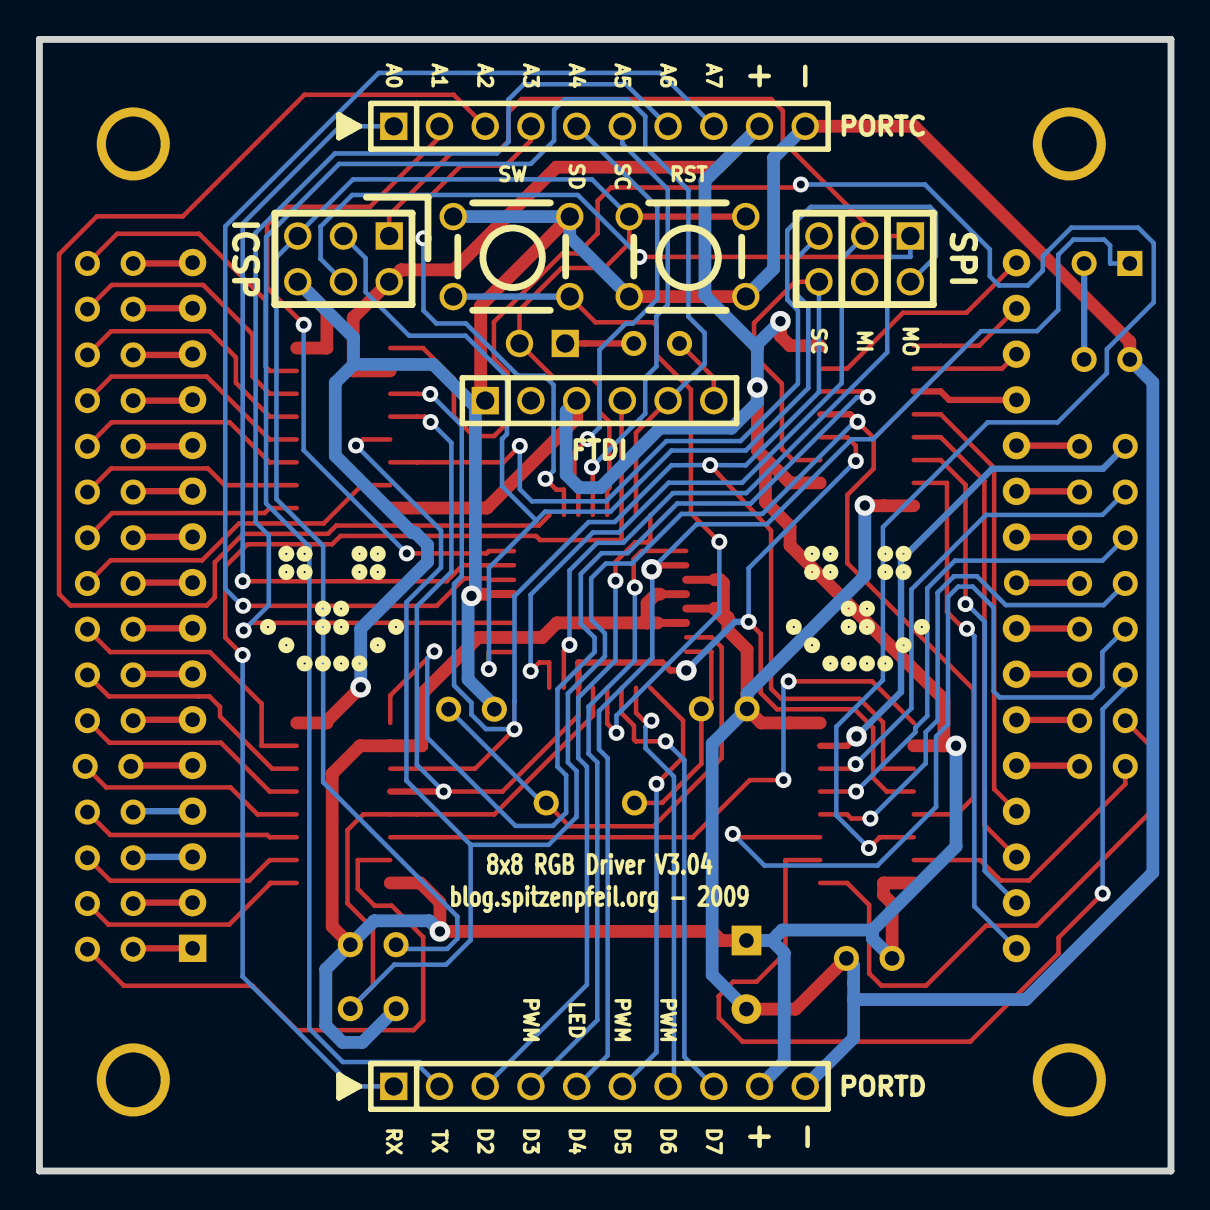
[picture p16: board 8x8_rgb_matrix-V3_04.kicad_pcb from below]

Board: 2 copper layers, 62.9 x 62.9 mm, 52 parts (7 on the bottom side), 91 nets.

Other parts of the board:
1PIN-1, 1PIN-2, 1PIN-3, 1PIN-4: P***; 1pin

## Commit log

2011-06-06 Added the assembly manual (pdf) and a link to the code repo.
2011-10-05 Renamed the schematic files for consistency reasons.
2013-01-23 Changed library path, so it doesn't use a symlink anymore.
    [8x8_rgb_matrix-V3_04.sch]
2013-01-25 Increased drill size for pin-headers to 40mil + recreated gerber files.
    Had to redo some of the routing due to clearance issues. Now it conforms
    to 8mil clearances. Also some of the auto-router traces were insane...
    [8x8_rgb_matrix-V3_04-routed.dsn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]
2013-06-28 Converted to new kicad board format.
    [8x8_rgb_matrix-V3_04.brd, 8x8_rgb_matrix-V3_04.kicad_pcb]
2014-11-26 Schematic fixed (pwr_flags, no-connects...) & LED-matrix (pins to passive).
    All layout-related files unchanged.
    [8x8_rgb_matrix-V3_04.sch]
